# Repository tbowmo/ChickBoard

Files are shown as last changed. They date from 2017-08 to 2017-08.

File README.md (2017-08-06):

# ChickBoard

A little background info: 
The plan is that all birds in our chicken coop have a RFID tag (using 
125Khz TK4100 tags). Each nest then have an EM4100 RFID reader module,
so I can follow the birds between all nests. 

Because the nests are not placed near each other, I have settled on RS485
for nest communication. It's also planned to have a LED strip or two in the
ceiling, to give a little light in the dark winter nights.

This board is meant as a multipurpose board for this project, so it can be
used in a couple of different situations:

1) RFID reader (EM4100)
2) 1wire bus (can be used with DS1820 to measure temperature)
3) 2 x LED drivers (fet transistors)
4) RS485 bus for communication
5) Atmel ATSAMD20 (upto 256Kb flash)
6) MYSX 2.2 board extension board connector

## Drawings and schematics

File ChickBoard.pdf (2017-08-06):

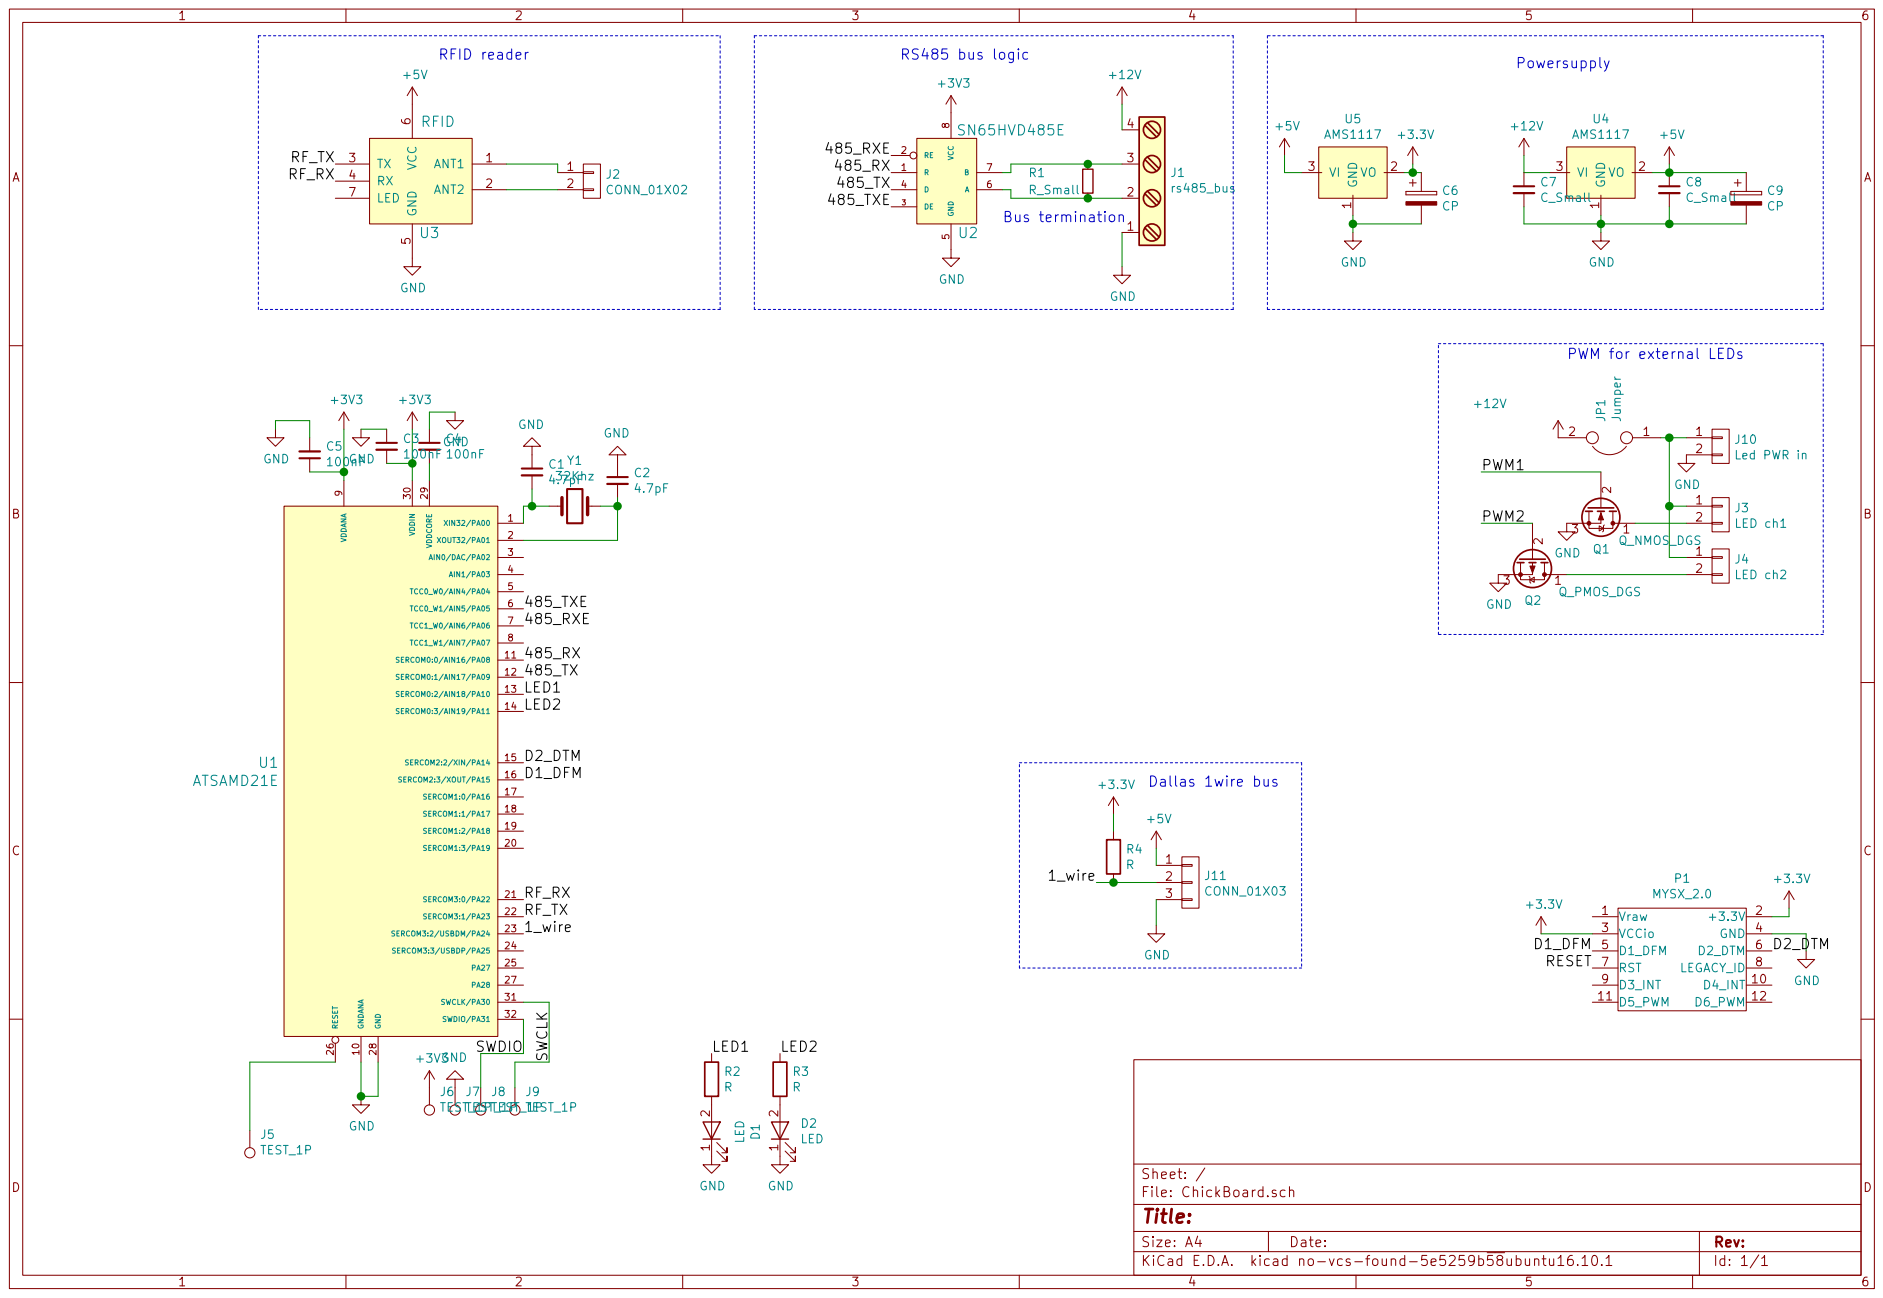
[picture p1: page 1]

1 VO 2 VI 3 U5 AMS1117 +5V +3.3V GND GND

Id: 1/1 Title: File: ChickBoard.sch Sheet: /

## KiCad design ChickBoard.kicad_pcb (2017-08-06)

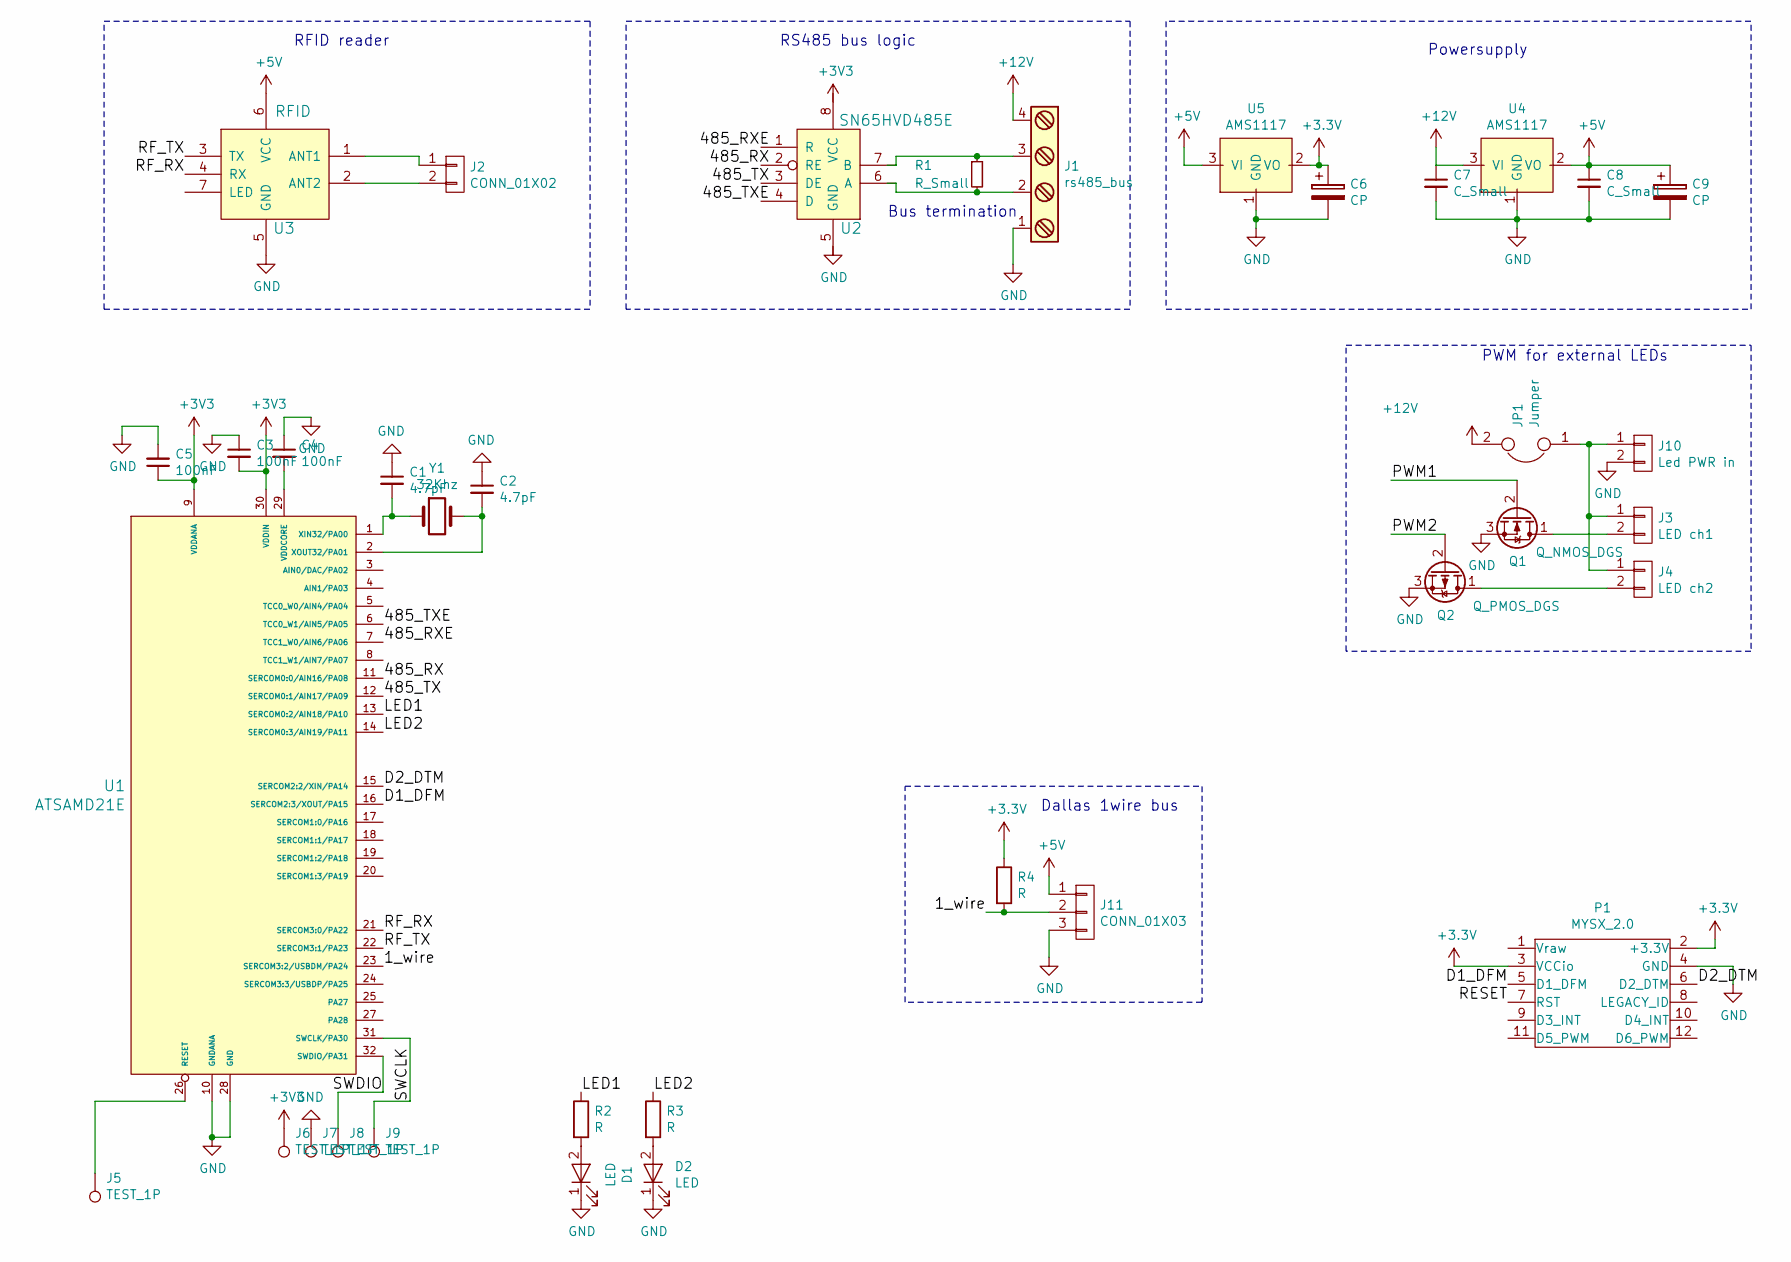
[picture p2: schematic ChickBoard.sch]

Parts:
C1, C2: 4.7pF; C_0603_HandSoldering
C3, C4, C5: 100nF; C_0603_HandSoldering
C6, C9: CP; C_0603_HandSoldering
C7, C8: C_Small; C_0603_HandSoldering
D1, D2: LED; LED-0603
J1: rs485_bus; TerminalBlock_Pheonix_MPT-2.54mm_4pol
J2: CONN_01X02; Pin_Header_Straight_1x02
J3: LED ch1; TerminalBlock_Pheonix_MPT-2.54mm_2pol
J4: LED ch2; TerminalBlock_Pheonix_MPT-2.54mm_2pol
J5, J6, J7, J8, J9: TEST_1P; Measurement_Point_Round-SMD-Pad_Small
J10: Led PWR in; TerminalBlock_Pheonix_MPT-2.54mm_2pol
J11: CONN_01X03; TerminalBlock_Pheonix_MPT-2.54mm_3pol
JP1: Jumper; 2_pin_solder_jumper_smd
P1: MYSX_2.0; MYSX_2.2
Q1: Q_NMOS_DGS; SOT-23
Q2: Q_PMOS_DGS; SOT-23
R1: R_Small; R_0603_HandSoldering
R2, R3, R4: R; R_0603_HandSoldering
U1: ATSAMD21E; TQFP-32_7x7mm_Pitch0.8mm
U2: SN65HVD485E; SOIJ-8_5.3x5.3mm_Pitch1.27mm
U3: RFID; EM4100RFID
U4, U5: AMS1117; SOT-23
Y1: 32Khz; XTAL_3.2x1.5mm

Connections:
+5V: C8.1, C9.1, J11.1, U3.6 (VCC), U4.2 (VO), U5.3 (VI)
+12V: C7.1, J1.4, JP1.2, U4.3 (VI)
/1_wire: J11.2, R4.2, U1.23 (SERCOM3:2/USBDM/PA24)
/485_RX: U1.11 (SERCOM0:0/AIN16/PA08), U2.1 (R)
/485_RXE: U1.7 (TCC1_W0/AIN6/PA06), U2.2 (RE)
/485_TX: U1.12 (SERCOM0:1/AIN17/PA09), U2.4 (D)
/485_TXE: U1.6 (TCC0_W1/AIN5/PA05), U2.3 (DE)
/D1_DFM: P1.5 (D1_DFM), U1.16 (SERCOM2:3/XOUT/PA15)
/D2_DTM: P1.6 (D2_DTM), U1.15 (SERCOM2:2/XIN/PA14)
/LED1: R2.1, U1.13 (SERCOM0:2/AIN18/PA10)
/LED2: R3.1, U1.14 (SERCOM0:3/AIN19/PA11)
/PWM1: Q1.2 (G)
/PWM2: Q2.2 (G)
/RESET: P1.7 (RST)
/RF_RX: U1.21 (SERCOM3:0/PA22), U3.4 (RX)
/RF_TX: U1.22 (SERCOM3:1/PA23), U3.3 (TX)
/SWCLK: J9.1, U1.31 (SWCLK/PA30)
/SWDIO: J8.1, U1.32 (SWDIO/PA31)
GND: C1.1, C2.1, C3.1, C4.1, C5.2, C6.2, C7.2, C8.2, C9.2, D1.1 (K), D2.1 (K), J1.1, J7.1, J10.2, J11.3, P1.4 (GND), Q1.3 (S), Q2.3 (S), U1.10 (GNDANA), U1.28 (GND), U2.5 (GND), U3.5 (GND), U4.1 (GND), U5.1 (GND)
unnamed: C1.2, U1.1 (XIN32/PA00), Y1.1
unnamed: C2.2, U1.2 (XOUT32/PA01), Y1.2
unnamed: C4.2, U1.29 (VDDCORE)
unnamed: D1.2 (A), R2.2
unnamed: D2.2 (A), R3.2
unnamed: J1.2, R1.2, U2.6 (A)
unnamed: J1.3, R1.1, U2.7 (B)
unnamed: J2.1, U3.1 (ANT1)
unnamed: J2.2, U3.2 (ANT2)
unnamed: J3.2, Q1.1 (D)
unnamed: J4.2, Q2.1 (D)
unnamed: J5.1, U1.26 (RESET)
unnamed: J3.1, J4.1, J10.1, JP1.1

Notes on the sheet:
Bus termination
Dallas 1wire bus
Powersupply
RS485 bus logic
RFID reader
PWM for external LEDs

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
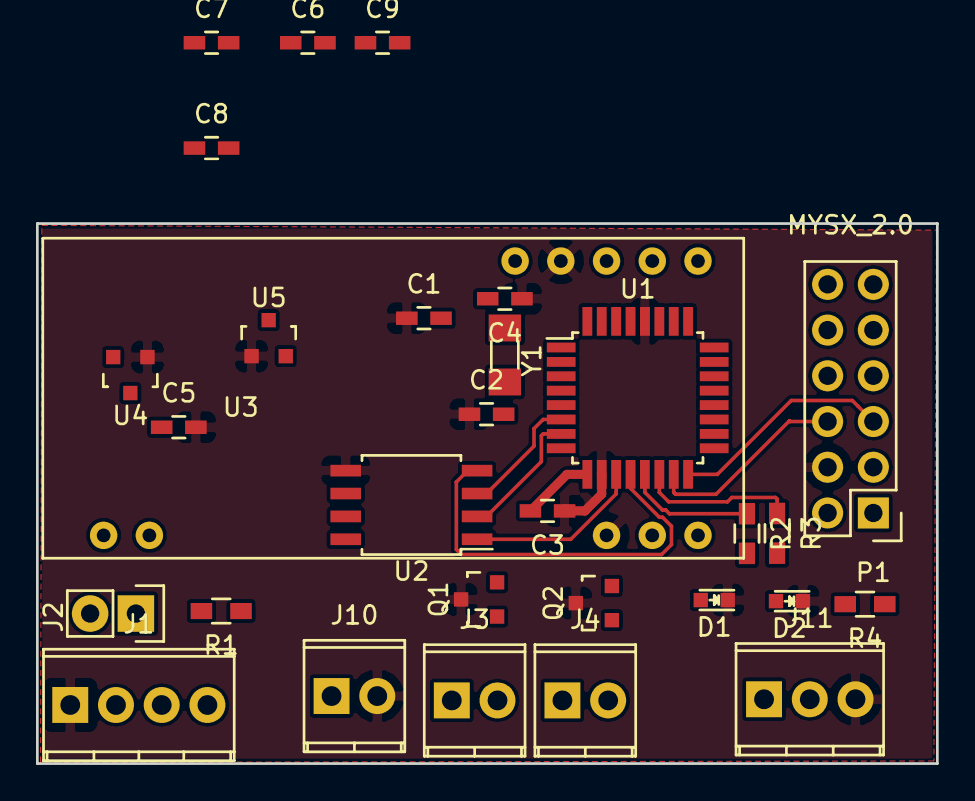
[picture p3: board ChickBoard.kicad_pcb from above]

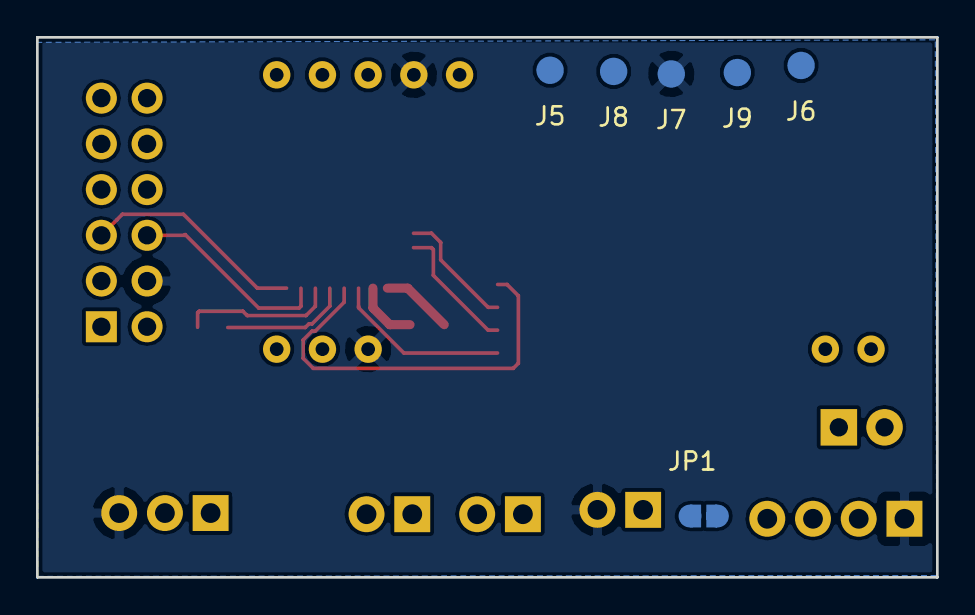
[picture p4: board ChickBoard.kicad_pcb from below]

Board: 2 copper layers, 50.0 x 30.0 mm, 36 parts (6 on the bottom side), 30 nets.
